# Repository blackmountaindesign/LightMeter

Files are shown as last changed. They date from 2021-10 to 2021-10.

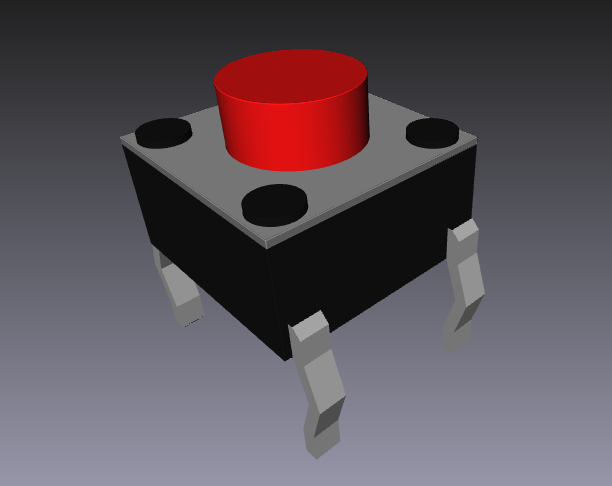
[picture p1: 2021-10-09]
Assemblies/pushbutton-red-1.snapshot.3/Button_red_s0_persp.png

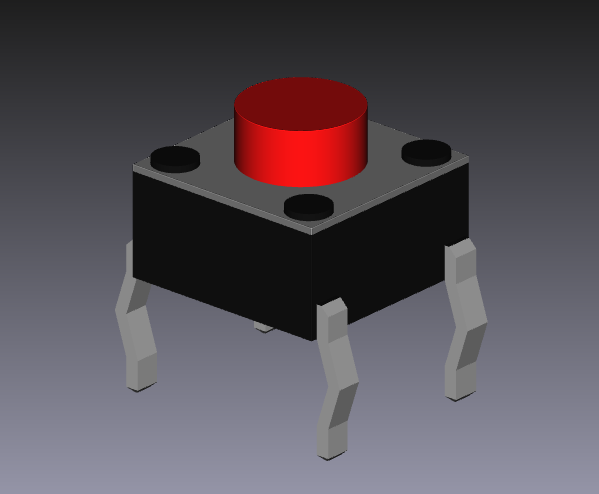
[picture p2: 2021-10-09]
Assemblies/pushbutton-red-1.snapshot.3/Button_red_s0.png

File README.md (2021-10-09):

# lightmeter
A Lightmeter/Flashmeter for photographers, based on Arduino.

Components:
1. Arduino NANO v.3 https://www.banggood.com/custlink/K3Kvbdnnea
2. BH1750 light sensor https://www.banggood.com/custlink/mKDv2Ip1dr or https://www.banggood.com/custlink/GvGvnRNN0e
3. SSD1306 128*64 OLED SPI Display https://www.banggood.com/custlink/DDKmsdAQ6z
4. Buttons https://www.banggood.com/custlink/m3DGAYsnnY
5. 50x70 PCB https://www.banggood.com/custlink/KvvvnybQAP
6. AAA battery Holder https://www.banggood.com/custlink/vK3KsynANN

Thanks @morozgrafix https://github.com/morozgrafix for creating schematic diagram for this device.

The lightmeter based on Arduino as a main controller and BH1750 as a metering cell. Information is displayed on SSD1306 OLED display. The device is powered by 2 AAA batteries.

Functions list:

* Ambient light metering
* Flash light metering
* ND filter correction
* Aperture priority
* Shutter speed priority
* ISO range 8 - 4 000 000
* Aperture range 1.0 - 3251
* Shutter speed range 1/10000 - 133 sec
* ND Filter range ND2 - ND8192
* Displaying amount of light in Lux.
* Displaying exposure value, EV
* Recalculating exposure pair while one of the parameter changing
* Battery information
* Power 2xAAA LR03 batteries

Detailed information on my site: https://www.pominchuk.com/lightmeter/

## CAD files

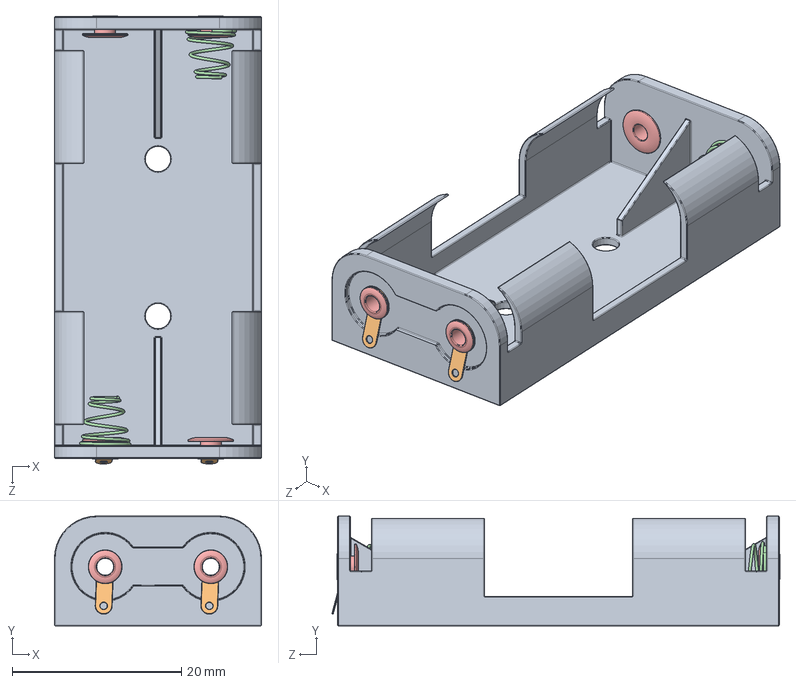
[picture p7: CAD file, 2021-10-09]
Assemblies/Battery_Holder_Assembly/Batterilada.SLDASM
24.5 x 13.0 x 53.0 mm
chassi
ring x 2
bleck
spring x 2
koppar x 4

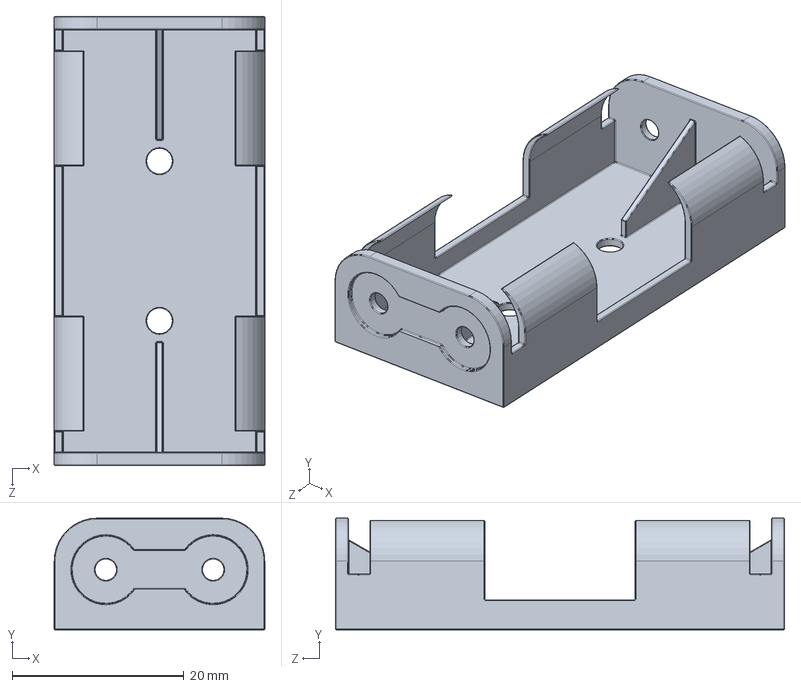
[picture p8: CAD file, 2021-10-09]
Assemblies/Battery_Holder_Assembly/chassi.SLDPRT
24.5 x 13.0 x 52.2 mm

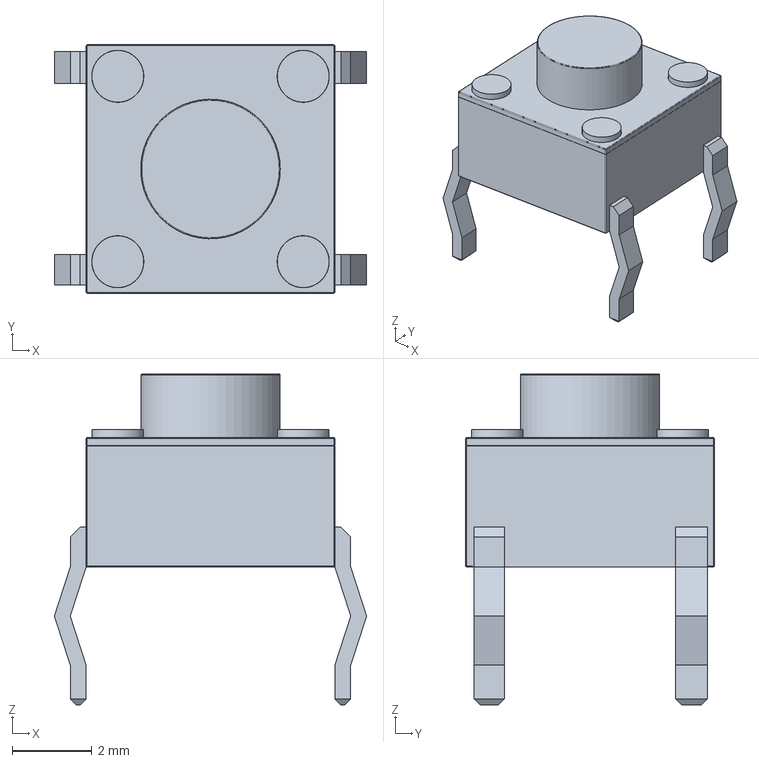
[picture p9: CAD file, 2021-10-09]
Assemblies/pushbutton-red-1.snapshot.3/Button_rot.FCStd
7.85 x 6.25 x 8.32 mm

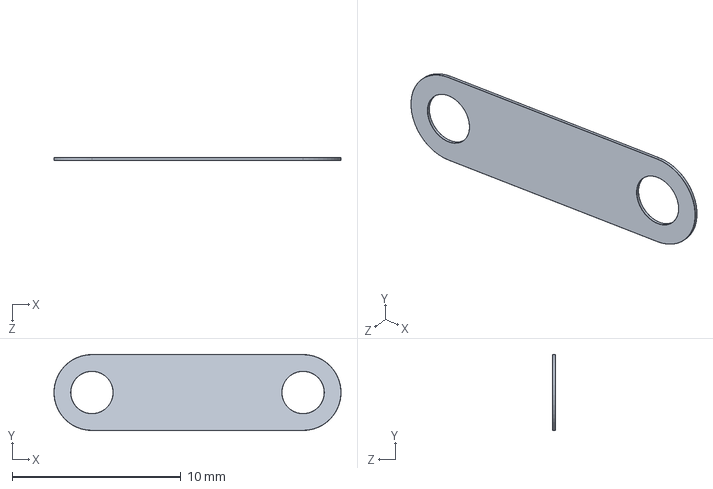
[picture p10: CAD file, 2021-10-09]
Assemblies/Battery_Holder_Assembly/bleck.SLDPRT
17.0 x 4.50 x 0.15 mm

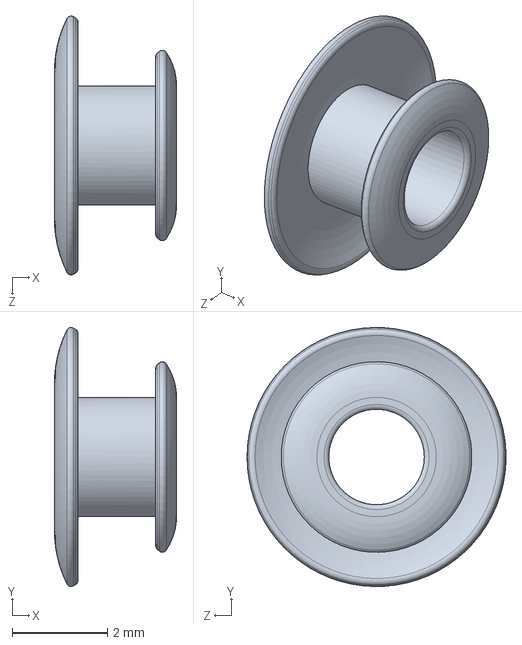
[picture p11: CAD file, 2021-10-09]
Assemblies/Battery_Holder_Assembly/koppar.SLDPRT
2.56 x 5.42 x 5.42 mm

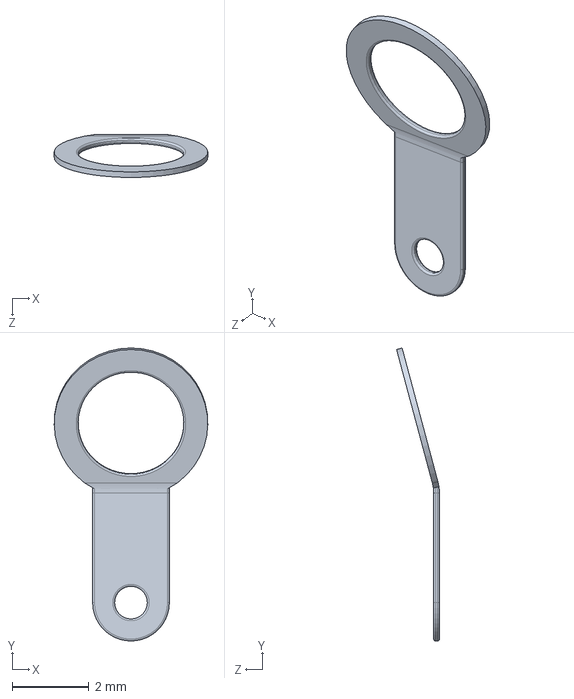
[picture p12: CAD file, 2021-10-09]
Assemblies/Battery_Holder_Assembly/ring.SLDPRT
4.00 x 7.63 x 1.12 mm

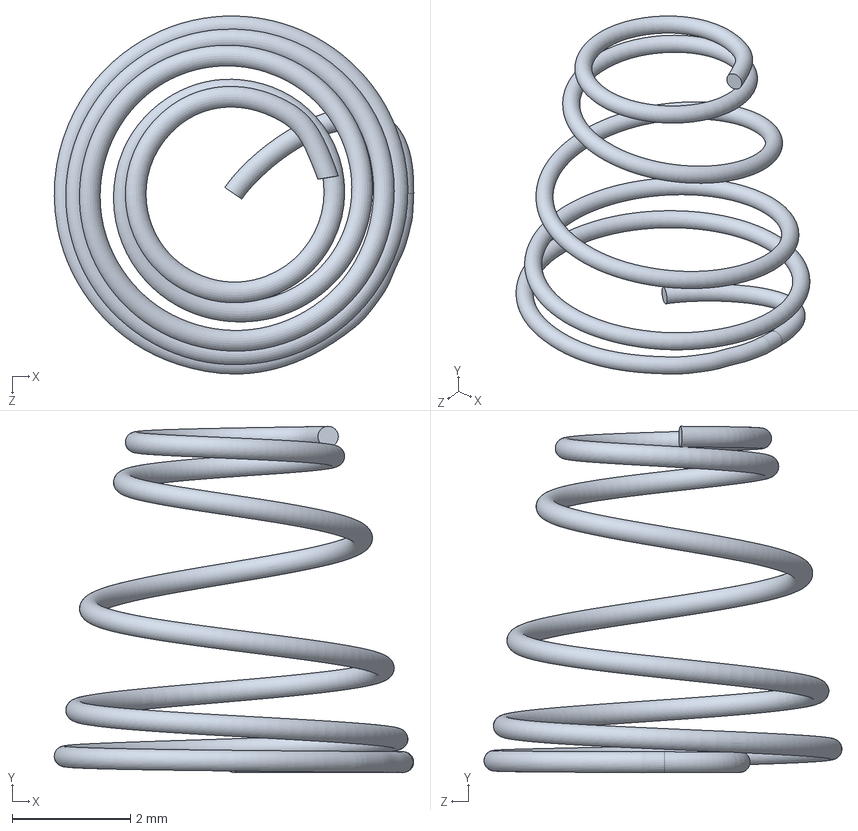
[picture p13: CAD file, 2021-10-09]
Assemblies/Battery_Holder_Assembly/spring.SLDPRT
6.08 x 5.86 x 6.05 mm

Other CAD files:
Assemblies/pushbutton-red-1.snapshot.3/Button_red.step
Assemblies/Arduino_Nano_Parts/102 RESISTOR PACK.ipt
Assemblies/Arduino_Nano_Parts/15pin_header__.ipt
Assemblies/Arduino_Nano_Parts/16mhz crystal - measured.ipt
Assemblies/Arduino_Nano_Parts/189 RESISTOR PACK.ipt
Assemblies/Arduino_Nano_Parts/2pin_header__02.ipt
Assemblies/Arduino_Nano_Parts/MINI USB CONTACT.ipt
Assemblies/Arduino_Nano_Parts/MINIUSBCORE.ipt
Assemblies/Arduino_Nano_Parts/MINIUSBSHELL.ipt
Assemblies/Arduino_Nano_Parts/NANO DIODE.ipt
Assemblies/Arduino_Nano_Parts/OldVersions/arduino nano.0001.iam
Assemblies/Arduino_Nano_Parts/arduino nano.iam
Assemblies/Arduino_Nano_Parts/cap106C.ipt
Assemblies/Arduino_Nano_Parts/ftdi FT232rl.ipt
Assemblies/Arduino_Nano_Parts/led.ipt
Assemblies/Arduino_Nano_Parts/nano - reg.ipt
Assemblies/Arduino_Nano_Parts/nano-board.ipt
Assemblies/Arduino_Nano_Parts/reset core.ipt
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

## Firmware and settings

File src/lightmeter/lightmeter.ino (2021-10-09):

#include <SPI.h>
#include <Wire.h>
#include <Adafruit_GFX.h>
#include <Adafruit_SSD1306.h>
#include <BH1750.h>
#include <EEPROM.h>
#include <avr/sleep.h>

#define OLED_DC                 11
#define OLED_CS                 12
#define OLED_CLK                8 //10
#define OLED_MOSI               9 //9
#define OLED_RESET              10 //13
#define SCREEN_WIDTH 128 // OLED display width, in pixels
#define SCREEN_HEIGHT 64 // OLED display height, in pixels

Adafruit_SSD1306 display(SCREEN_WIDTH, SCREEN_HEIGHT, OLED_MOSI, OLED_CLK, OLED_DC, OLED_RESET, OLED_CS);

BH1750 lightMeter;

//#define DomeMultiplier          2.17                    // Multiplier when using a white translucid Dome covering the lightmeter
#define DomeMultiplier          1
#define MeteringButtonPin       2                       // Metering button pin
#define PlusButtonPin           3                       // Plus button pin
#define MinusButtonPin          4                       // Minus button pin
#define ModeButtonPin           5                       // Mode button pin
#define MenuButtonPin           6                       // ISO button pin
#define MeteringModeButtonPin   7                       // Metering Mode (Ambient / Flash)
//#define PowerButtonPin          2

#define MaxISOIndex             57
#define MaxApertureIndex        70
#define MaxTimeIndex            80
#define MaxNDIndex              13
#define MaxFlashMeteringTime    5000                    // ms

float   lux;
boolean Overflow = 0;                                   // Sensor got Saturated and Display "Overflow"
float   ISOND;
boolean ISOmode = 0;
boolean NDmode = 0;

boolean PlusButtonState;                // "+" button state
boolean MinusButtonState;               // "-" button state
boolean MeteringButtonState;            // Metering button state
boolean ModeButtonState;                // Mode button state
boolean MenuButtonState;                // ISO button state
boolean MeteringModeButtonState;        // Metering mode button state (Ambient / Flash)

boolean ISOMenu = false;
boolean NDMenu = false;
boolean mainScreen = false;

// EEPROM for memory recording
#define ISOIndexAddr        1
#define apertureIndexAddr   2
#define modeIndexAddr       3
#define T_expIndexAddr      4
#define meteringModeAddr    5
#define ndIndexAddr         6

#define defaultApertureIndex 12
#define defaultISOIndex      11
#define defaultModeIndex     0
#define defaultT_expIndex    19

uint8_t ISOIndex =          EEPROM.read(ISOIndexAddr);
uint8_t apertureIndex =     EEPROM.read(apertureIndexAddr);
uint8_t T_expIndex =        EEPROM.read(T_expIndexAddr);
uint8_t modeIndex =         EEPROM.read(modeIndexAddr);
uint8_t meteringMode =      EEPROM.read(meteringModeAddr);
uint8_t ndIndex =           EEPROM.read(ndIndexAddr);

int battVolts;
#define batteryInterval 10000
double lastBatteryTime = 0;

#include "lightmeter.h"

void setup() {  
  pinMode(PlusButtonPin, INPUT_PULLUP);
  pinMode(MinusButtonPin, INPUT_PULLUP);
  pinMode(MeteringButtonPin, INPUT_PULLUP);
  pinMode(ModeButtonPin, INPUT_PULLUP);
  pinMode(MenuButtonPin, INPUT_PULLUP);
  pinMode(MeteringModeButtonPin, INPUT_PULLUP);

  //Serial.begin(115200);

  battVolts = getBandgap();  //Determins what actual Vcc is, (X 100), based on known bandgap voltage

  Wire.begin();
  lightMeter.begin(BH1750::ONE_TIME_HIGH_RES_MODE_2);
  //lightMeter.begin(BH1750::ONE_TIME_LOW_RES_MODE); // for low resolution but 16ms light measurement time.

  display.begin(SSD1306_SWITCHCAPVCC, 0x3D);
  display.setTextColor(WHITE);
  display.clearDisplay();

  // IF NO MEMORY WAS RECORDED BEFORE, START WITH THIS VALUES otherwise it will read "255"
  if (apertureIndex > MaxApertureIndex) {
    apertureIndex = defaultApertureIndex;
  }

  if (ISOIndex > MaxISOIndex) {
    ISOIndex = defaultISOIndex;
  }

  if (T_expIndex > MaxTimeIndex) {
    T_expIndex = defaultT_expIndex;
  }

  if (modeIndex < 0 || modeIndex > 1) {
    // Aperture priority. Calculating shutter speed.
    modeIndex = 0;
  }

  if (meteringMode > 1) {
    meteringMode = 0;
  }

  if (ndIndex > MaxNDIndex) {
    ndIndex = 0;
  }

  lux = getLux();
  refresh();
}

void loop() {  
  if (millis() >= lastBatteryTime + batteryInterval) {
    lastBatteryTime = millis();
    battVolts = getBandgap();
  }
  
  readButtons();

  menu();

  if (MeteringButtonState == 0) {
    // Save setting if Metering button pressed.
    SaveSettings();

    lux = 0;
    refresh();
    
    if (meteringMode == 0) {
      // Ambient light meter mode.
      lightMeter.configure(BH1750::ONE_TIME_HIGH_RES_MODE_2);

      lux = getLux();

      if (Overflow == 1) {
        delay(10);
        getLux();
      }

      refresh();
      delay(200);
    } else if (meteringMode == 1) {
      // Flash light metering
      lightMeter.configure(BH1750::CONTINUOUS_LOW_RES_MODE);

      unsigned long startTime = millis();
      uint16_t currentLux = 0;
      lux = 0;

      while (true) {
        // check max flash metering time
        if (startTime + MaxFlashMeteringTime < millis()) {
          break;
        }

        currentLux = getLux();
        delay(16);
        
        if (currentLux > lux) {
          lux = currentLux;
        }
      }

      refresh();
    }
  }
}

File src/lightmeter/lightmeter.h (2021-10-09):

void outOfrange() {
  display.println(F("--"));
}

void SaveSettings() {
  // Save lightmeter setting into EEPROM.
  EEPROM.write(ndIndexAddr, ndIndex);
  EEPROM.write(ISOIndexAddr, ISOIndex);
  EEPROM.write(modeIndexAddr, modeIndex);
  EEPROM.write(apertureIndexAddr, apertureIndex);
  EEPROM.write(T_expIndexAddr, T_expIndex);
  EEPROM.write(meteringModeAddr, meteringMode);
}

// Returns actual value of Vcc (x 100)
int getBandgap(void) {
#if defined(__AVR_ATmega1280__) || defined(__AVR_ATmega2560__)
  // For mega boards
  const long InternalReferenceVoltage = 1115L;  // Adjust this value to your boards specific internal BG voltage x1000
  // REFS1 REFS0          --> 0 1, AVcc internal ref. -Selects AVcc reference
  // MUX4 MUX3 MUX2 MUX1 MUX0  --> 11110 1.1V (VBG)         -Selects channel 30, bandgap voltage, to measure
  ADMUX = (0 << REFS1) | (1 << REFS0) | (0 << ADLAR) | (0 << MUX5) | (1 << MUX4) | (1 << MUX3) | (1 << MUX2) | (1 << MUX1) | (0 << MUX0);

#else
  // For 168/328 boards
  const long InternalReferenceVoltage = 1056L;  // Adjust this value to your boards specific internal BG voltage x1000
  // REFS1 REFS0          --> 0 1, AVcc internal ref. -Selects AVcc external reference
  // MUX3 MUX2 MUX1 MUX0  --> 1110 1.1V (VBG)         -Selects channel 14, bandgap voltage, to measure
  ADMUX = (0 << REFS1) | (1 << REFS0) | (0 << ADLAR) | (1 << MUX3) | (1 << MUX2) | (1 << MUX1) | (0 << MUX0);

#endif
  delay(50);  // Let mux settle a little to get a more stable A/D conversion
  // Start a conversion
  ADCSRA |= _BV( ADSC );
  // Wait for it to complete
  while ( ( (ADCSRA & (1 << ADSC)) != 0 ) );
  // Scale the value
  int results = (((InternalReferenceVoltage * 1024L) / ADC) + 5L) / 10L; // calculates for straight line value

  return results;
}

void footer() {
  display.setCursor(0, 55);
  display.print(F("press M"));
}

/*
  Get light value
*/
float getLux() {
  uint16_t lux = lightMeter.readLightLevel();

  if (lux >= 65534) {
    // light sensor is overloaded.
    Overflow = 1;
    lux = 65535;
  } else {
    Overflow = 0;
  }

  return lux * DomeMultiplier;             // DomeMultiplier = 2.17 (calibration)*/
}

float log2(float x) {
  return log(x) / log(2);
}

float lux2ev(float lux) {
  return log2(lux / 2.5);
}

// return aperture value (1.4, 1.8, 2.0) by index in sequence (0, 1, 2, 3, ...).
float getApertureByIndex(uint8_t indx) {
  float roundIndx = 10.0;

  if (indx > 39) {
    roundIndx = 1;
  }

  float f = round(pow(2, indx / 3.0 * 0.5) * roundIndx) / roundIndx;

  // the formula returns exact value, but photographers uses more memorable values.
  // convert it.

  if (f >= 1.1 && f < 1.2) {
    f = 1.1;
  } else if (f >= 1.2 && f < 1.4) {
    f = 1.2;
  } else if (f > 3.2 && f < 4) {
    f = 3.5;
  } else if (f > 5 && f < 6.3) {
    f = 5.6;
  } else if (f > 10 && f < 11) {
    f = 10;
  } else if (f >= 11 && f < 12) {
    f = 11;
  } else if (f >= 12 && f < 14) {
    f = 13;
  } else if (f >= 14 && f < 16) {
    f = 14;
  } else if (f >= 20 && f < 22) {
    f = 20;
  } else if (f >= 22 && f < 25) {
    f = 22;
  } else if (f >= 24 && f < 28) {
    f = 25;
  } else if (f >= 28 && f < 40) {
    f = 36;
  } else if (f >= 40 && f < 45) {
    f = 40;
  } else if (f >= 45 && f < 50) {
    f = 45;
  } else if (f >= 50 && f < 57) {
    f = 51;
  } else if (f >= 71 && f < 80) {
    f = 72;
  } else if (f >= 80 && f < 90) {
    f = 80;
  } else if (f >= 90 && f < 101) {
    f = 90;
  }

  return f;
}

// Return ISO value (100, 200, 400, ...) by index in sequence (0, 1, 2, 3, ...).
long getISOByIndex(uint8_t indx) {
  if (indx < 0 || indx > MaxISOIndex) {
    indx = 0;
  }

  indx += 10;

  //  float iso = pow(10, (indx - 1) / 10.0);
  //  iso = (long)(round(iso / 10.0) * 10);

  long int factor = 1;
  float iso = 0;

  if (indx > 60) {
    indx -= 50;
    factor = 100000;
  } else if (indx > 50) {
    indx -= 40;
    factor = 10000;
  } else if (indx > 40) {
    indx -= 30;
    factor = 1000;
  } else if (indx > 30) {
    indx -= 20;
    factor = 100;
  } else if (indx > 20) {
    indx -= 10;
    factor = 10;
  }

  if (indx == 10) {
    iso = 8;
  } else if (indx == 11) {
    iso = 10;
  } else if (indx == 12) {
    iso = 12.5;
  } else if (indx == 13) {
    iso = 16;
  } else if (indx == 14) {
    iso = 20;
  } else if (indx == 15) {
    iso = 25;
  } else if (indx == 16) {
    iso = 32;
  } else if (indx == 17) {
    iso = 40;
  } else if (indx == 18) {
    iso = 50;
  } else if (indx == 19) {
    iso = 64;
  } else if (indx == 20) {
    iso = 80;
  }

  iso = (long)floor(iso * factor);
  return iso;
}

float getMinDistance(float x, float v1, float v2) {
  if (x - v1 > v2 - x) {
    return v2;
  }

  return v1;
}

float getTimeByIndex(uint8_t indx) {
  if (indx < 0 || indx >= MaxTimeIndex) {
    indx = 0;
  }

  float factor = 0;
  float t = 0;

  if (indx < 10) {
    factor = 100.0;
  } else if (indx < 20) {
    indx -= 10;
    factor = 10.0;
  } else if (indx < 30) {
    indx -= 20;
    factor = 1.0;
  } else if (indx < 40) {
    indx -= 30;
    factor = 0.1;
  } else if (indx < 50) {
    indx -= 40;
    factor = 0.01;
  } else if (indx < 60) {
    indx -= 50;
    factor = 0.001;
  } else if (indx < 70) {
    indx -= 60;
    factor = 0.0001;
  } else if (indx < 80) {
    indx -= 70;
    factor = 0.00001;
  }

  if (indx == 0) {
    t = 100;
  } else if (indx == 1) {
    t = 80;
  } else if (indx == 2) {
    t = 64;
  } else if (indx == 3) {
    t = 50;
  } else if (indx == 4) {
    t = 40;
  } else if (indx == 5) {
    t = 32;
  } else if (indx == 6) {
    t = 25;
  } else if (indx == 7) {
    t = 20;
  } else if (indx == 8) {
    t = 16;
  } else if (indx == 9) {
    t = 12.5;
  }

  t = 1 / (t * factor);
  return t;
}
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
